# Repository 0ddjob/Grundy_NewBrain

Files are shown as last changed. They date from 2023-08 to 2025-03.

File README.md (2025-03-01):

# Grundy_NewBrain
Hopefully I can contribute something to the community.<br>

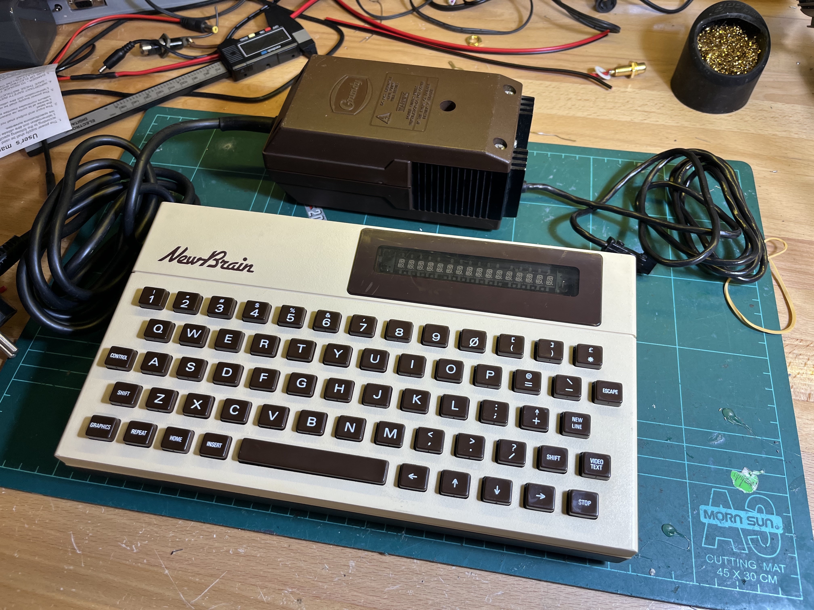
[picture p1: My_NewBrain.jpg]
My NewBrain


My current goal is to re-design the "store board" to use a 32KB SRAM instead of the two banks of 16KB DRAM.<br>

I think this is the last remaining fault in my machine.<br>

Failing ... or succeeding ... that, I'd like to try at a 64KB external SRAM board.<br>

{Fri 15-Sept-2023}<br>
Sent SRAM Store Board prototype for fabrication<br>
{Sat 1-Mar-2025}<br>
Well, what a disaster that was.  Fixed my (obvious) mistakes and have sent the updated design for fabrication.<br>

My YouTube video playlist - note, most are my very early videos so probably a bit rough:<br>
[https://www.youtube.com/playlist?list=PL5pwokf56wMKPswNvQZJsGPXETtgRD57M](https://www.youtube.com/playlist?list=PL5pwokf56wMKPswNvQZJsGPXETtgRD57M)

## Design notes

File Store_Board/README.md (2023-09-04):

# Grundy NewBrain Store Board

This is the internal RAM board in the NewBrain.<br>

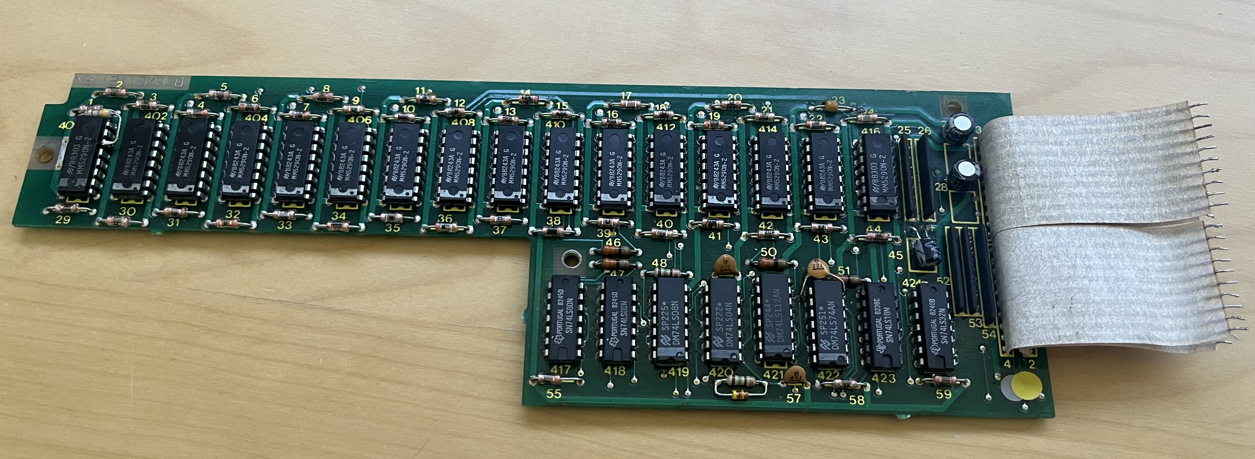
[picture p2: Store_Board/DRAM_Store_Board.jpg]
Original Store Board


It comprises two banks of 16KB, making 32KB in total.  Each bank has eight MM5290N-2 (16K x 1bit) DRAM chips.<br>

The DRAM is multiplexed using two RAS signals (RAS16 for bank 1 and RAS32 for bank 2) and one CAS signal.<br>

My idea to replace these DRAM with a single 32KB SRAM is as follows:<br>
- There are only eight address lines taken across to the store board: A0 to A6 & A14<br>
- As per other DRAM-to-SRAM designs, latch the RAS signals and apply with CAS<br>
- Simplify the two RAS16 & RAS32 signals to a single RAS signal for clocking the row address latch<br>

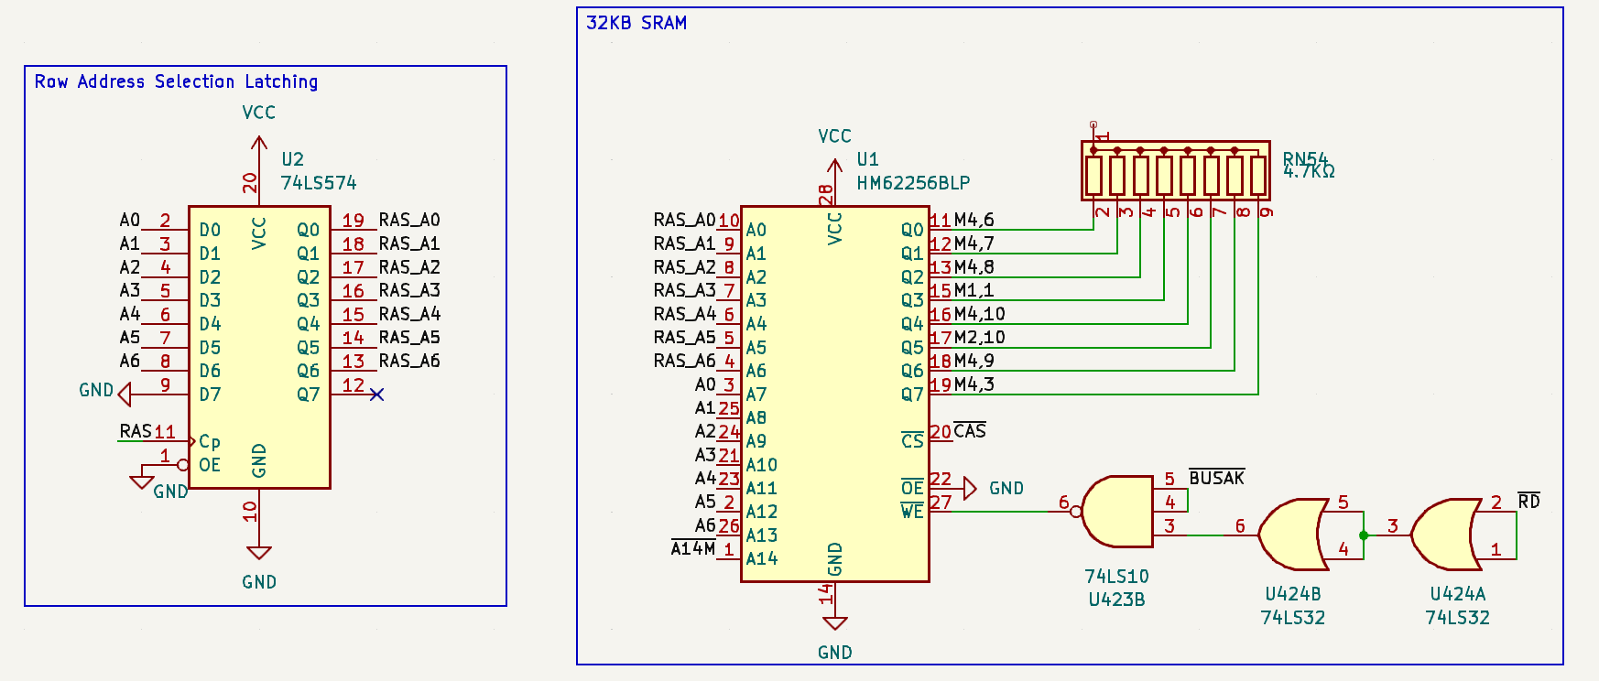
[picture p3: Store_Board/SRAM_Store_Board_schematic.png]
SRAM Store Board


Let's see ... (4-Sep-2023)<br>

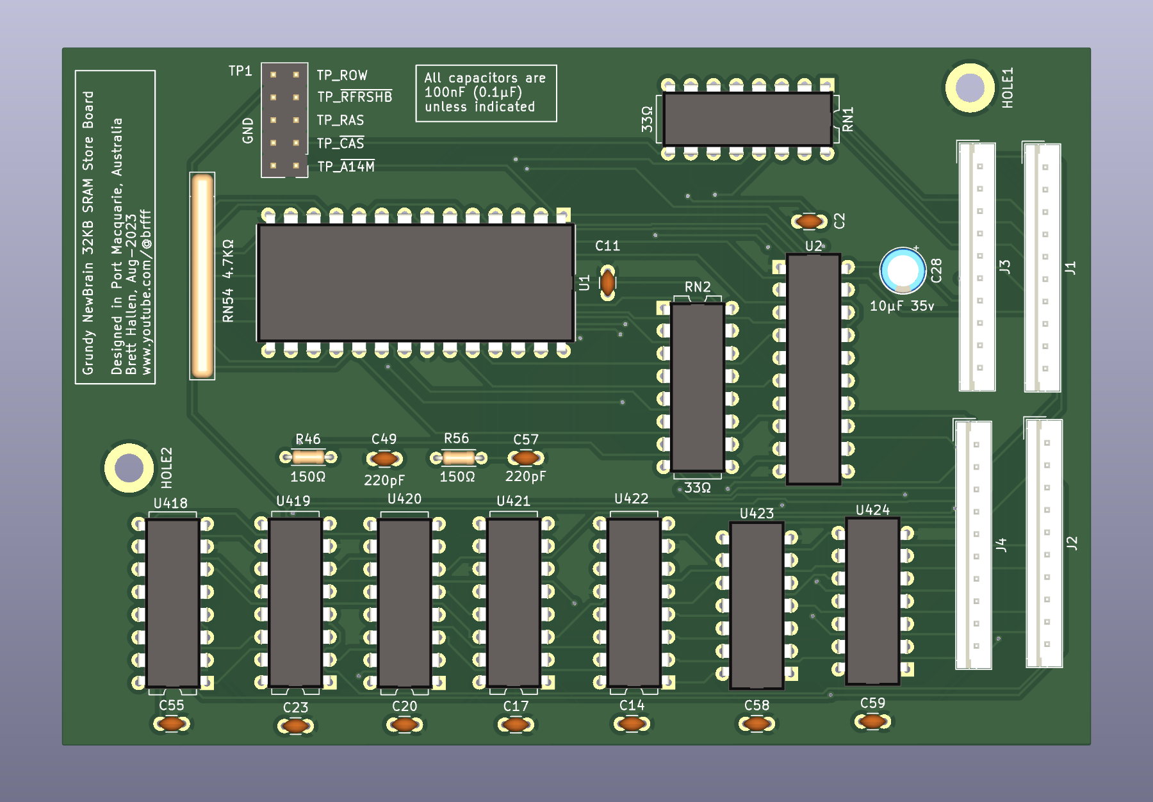
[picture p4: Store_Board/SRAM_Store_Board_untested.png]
SRAM Store Board PCB


Thanks to John Bradley for his Kicad schematics:<br>
https://github.com/flypie/NewBrain<br>

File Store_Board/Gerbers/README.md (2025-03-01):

# Grundy NewBrain Store Board

Please note that these are currently UNTESTED! <br>
Date: 1-Mar-2025 <br>

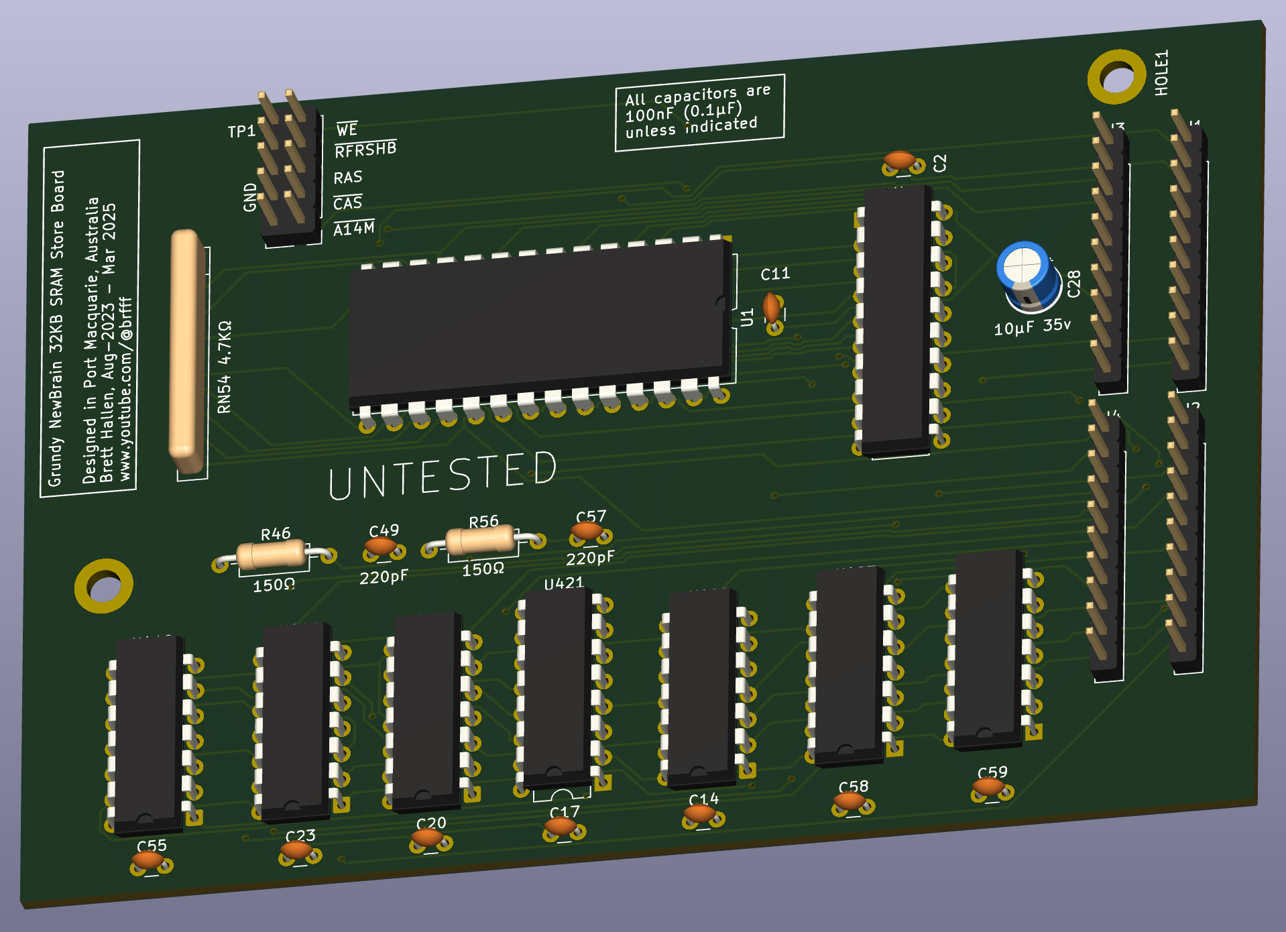
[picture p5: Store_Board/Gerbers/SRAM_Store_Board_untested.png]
SRAM Core Board


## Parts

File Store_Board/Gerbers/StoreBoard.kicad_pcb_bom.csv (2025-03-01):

Designator | Quantity | Value | Footprint | Package | MPN | DNP | Mount_Type
C11, C14, C17, C2, C20, C23, C55, C58, C59 | 9 | 100nF | C_Disc_D3.0mm_W1.6mm_P2.50mm |  |  |  | tht
C28 | 1 | 10µF 35v | CP_Radial_D5.0mm_P2.00mm |  |  |  | tht
C49, C57 | 2 | 220pF | C_Disc_D3.0mm_W1.6mm_P2.50mm |  |  |  | tht
HOLE1, HOLE2 | 2 | HOLE | MountingHole_3.2mm_M3_Pad |  |  |  | tht
J1, J2, J3, J4 | 4 | Conn_01x10 | PinHeader_1x10_P2.54mm_Vertical |  |  |  | tht
R46, R56 | 2 | 150Ω | R_Axial_DIN0207_L6.3mm_D2.5mm_P10.16mm_Horizontal |  |  |  | tht
RN54 | 1 | 4.7KΩ | R_Array_SIP9 |  |  |  | tht
TP1 | 1 | Conn_02x05_Odd_Even | PinHeader_2x05_P2.54mm_Vertical |  |  |  | tht
U1 | 1 | HM62256BLP | DIP-28_W15.24mm |  |  |  | tht
U2 | 1 | 74LS574 | DIP-20_W7.62mm |  |  |  | tht
U418 | 1 | 74LS00 | DIP-14_W7.62mm |  |  |  | tht
U419 | 1 | 74LS08 | DIP-14_W7.62mm |  |  |  | tht
U420 | 1 | 74LS04 | DIP-14_W7.62mm |  |  |  | tht
U421 | 1 | 74LS112 | DIP-16_W7.62mm |  |  |  | tht
U422 | 1 | SN74LS74 | DIP-14_W7.62mm |  |  |  | tht
U423 | 1 | 74LS10 | DIP-14_W7.62mm |  |  |  | tht
U424 | 1 | 74LS32 | DIP-14_W7.62mm |  |  |  | tht

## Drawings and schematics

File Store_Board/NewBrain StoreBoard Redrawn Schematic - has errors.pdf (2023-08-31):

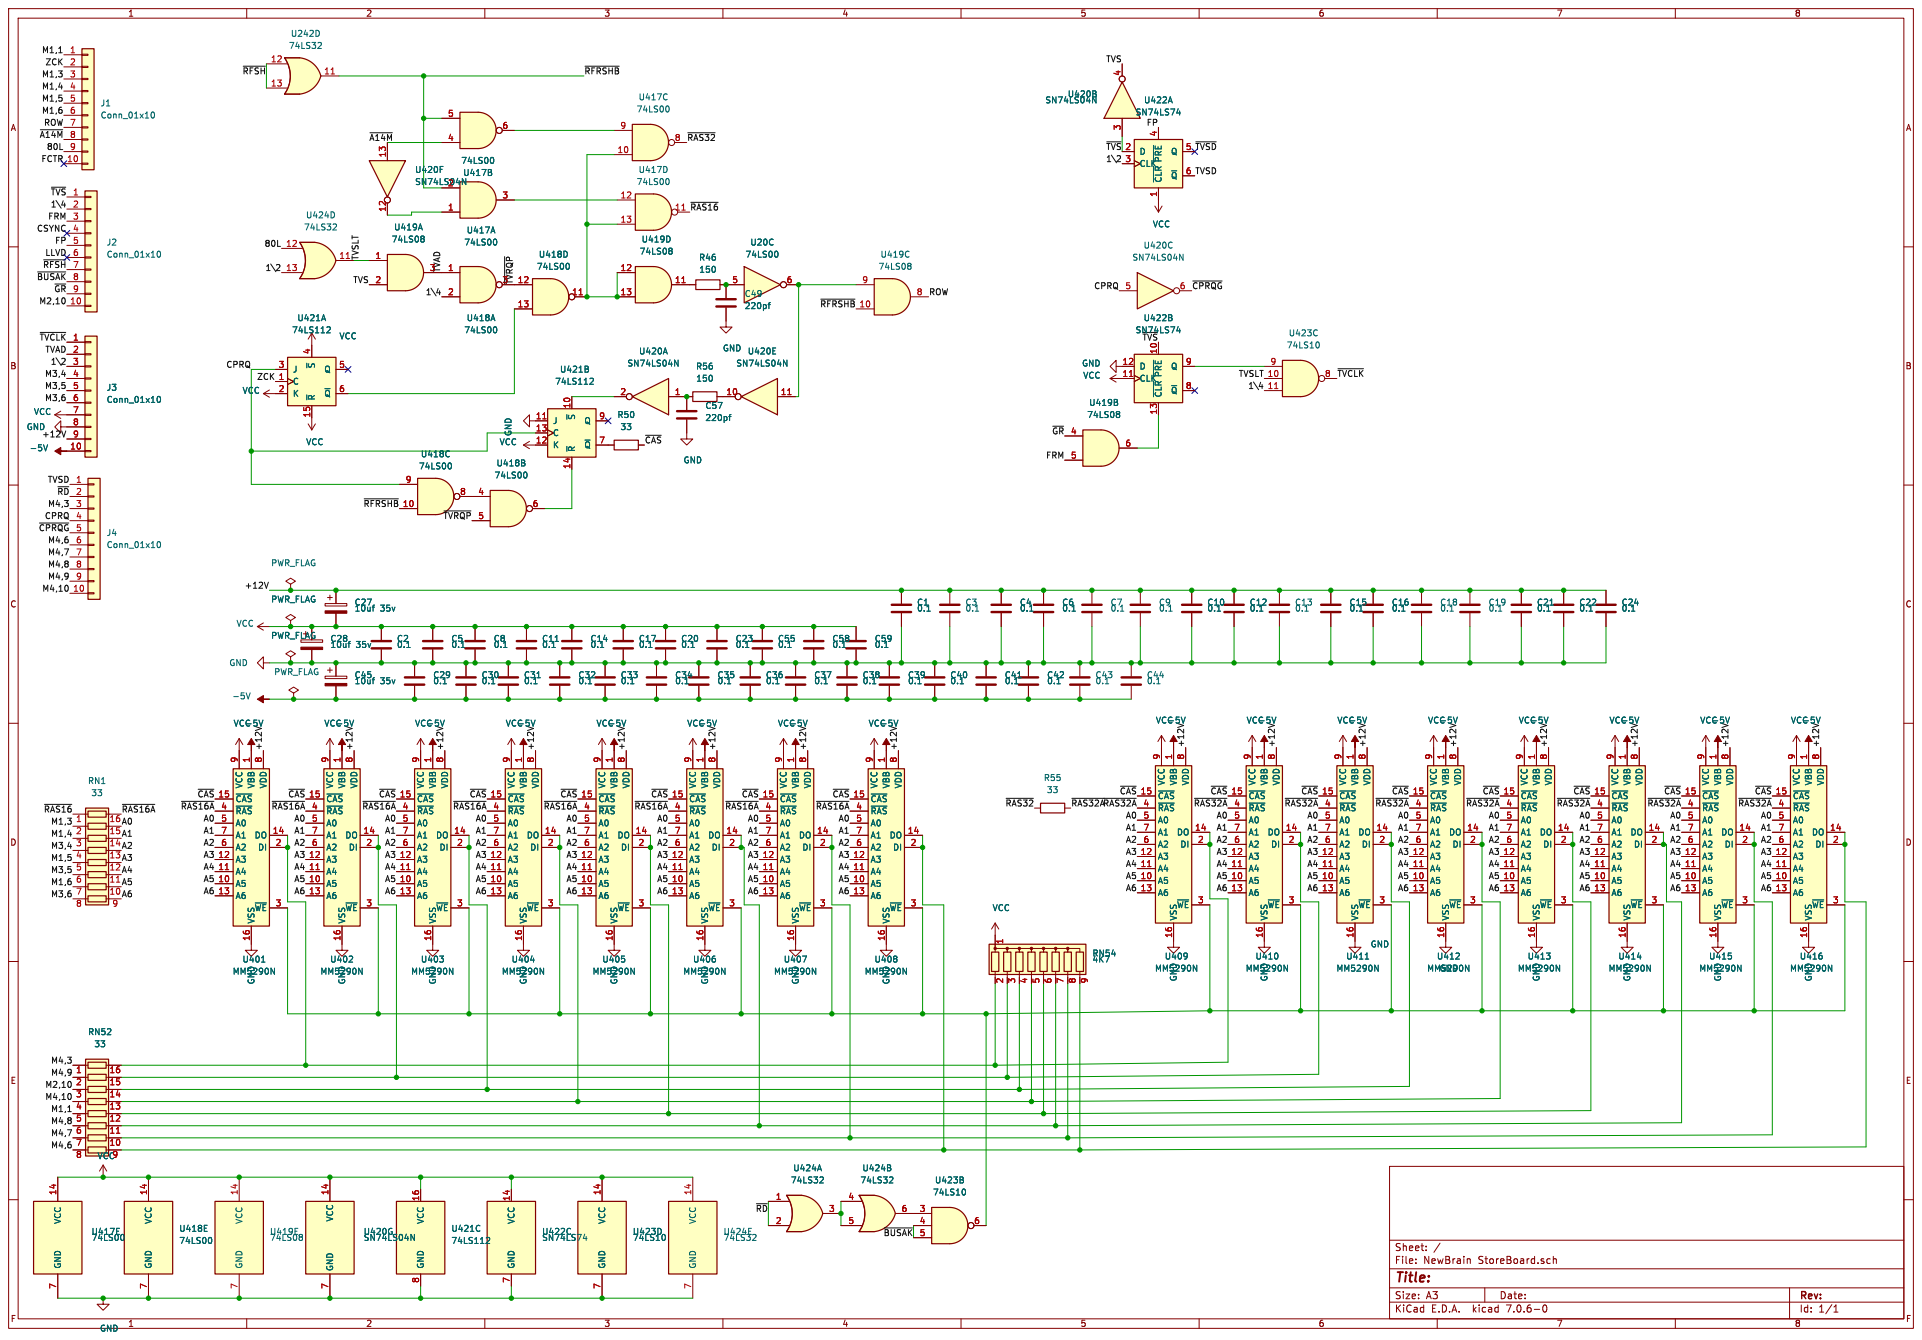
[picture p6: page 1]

7 VCC-5V VCC-5V GND GND

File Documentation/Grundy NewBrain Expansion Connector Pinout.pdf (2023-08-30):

1

49 | 25

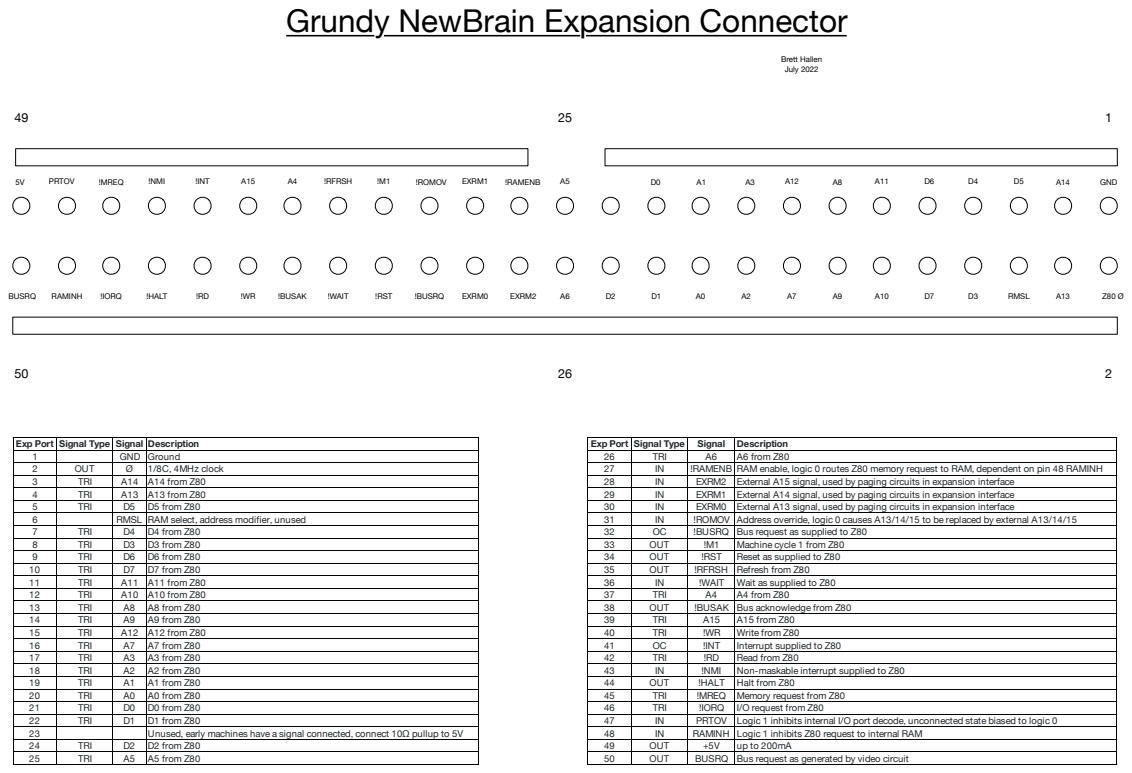
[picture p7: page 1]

Grundy NewBrain Expansion Connector

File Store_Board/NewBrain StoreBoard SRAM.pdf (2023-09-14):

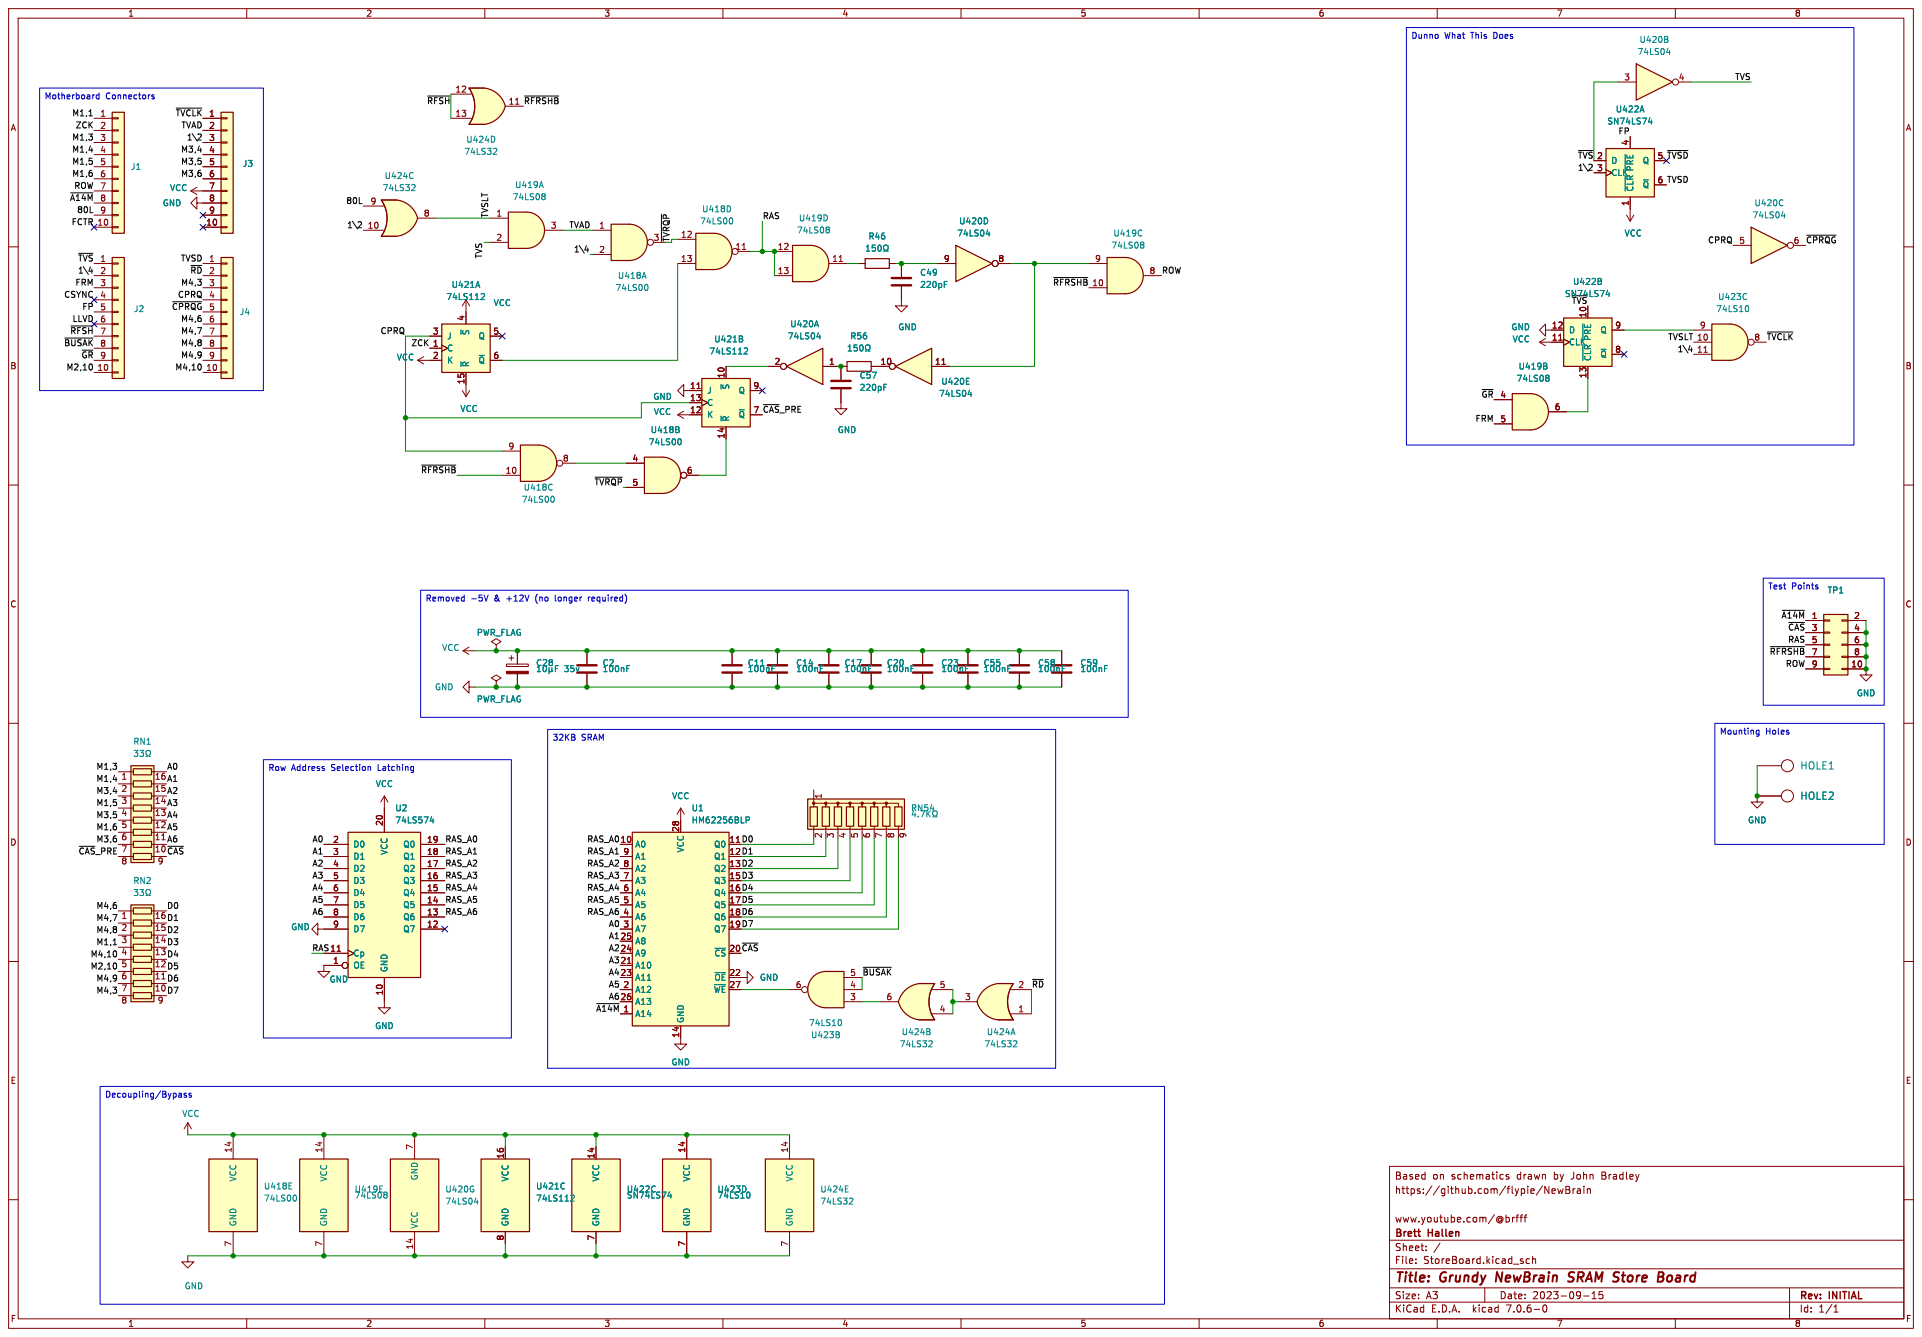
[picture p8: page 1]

~{TVSD} Removed -5V & +12V (no longer required)

Id: 1/1 Title: Grundy NewBrain SRAM Store Board

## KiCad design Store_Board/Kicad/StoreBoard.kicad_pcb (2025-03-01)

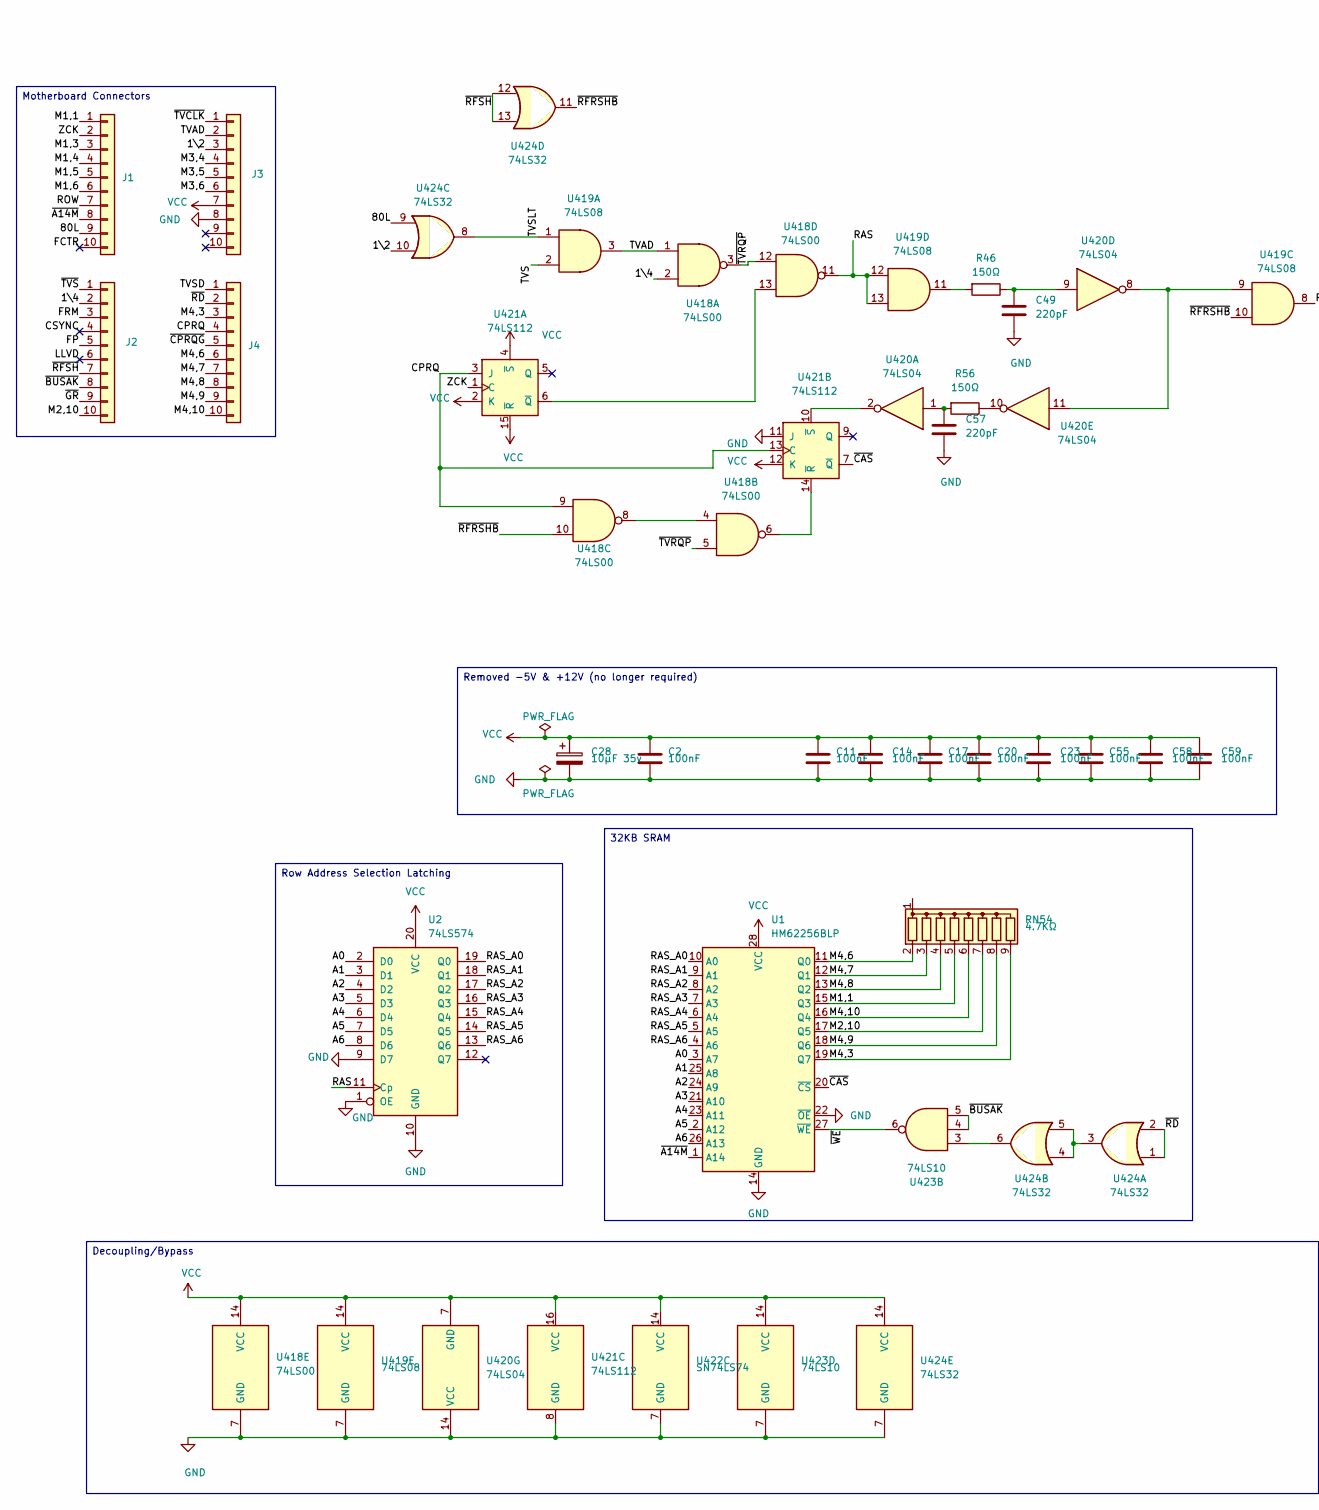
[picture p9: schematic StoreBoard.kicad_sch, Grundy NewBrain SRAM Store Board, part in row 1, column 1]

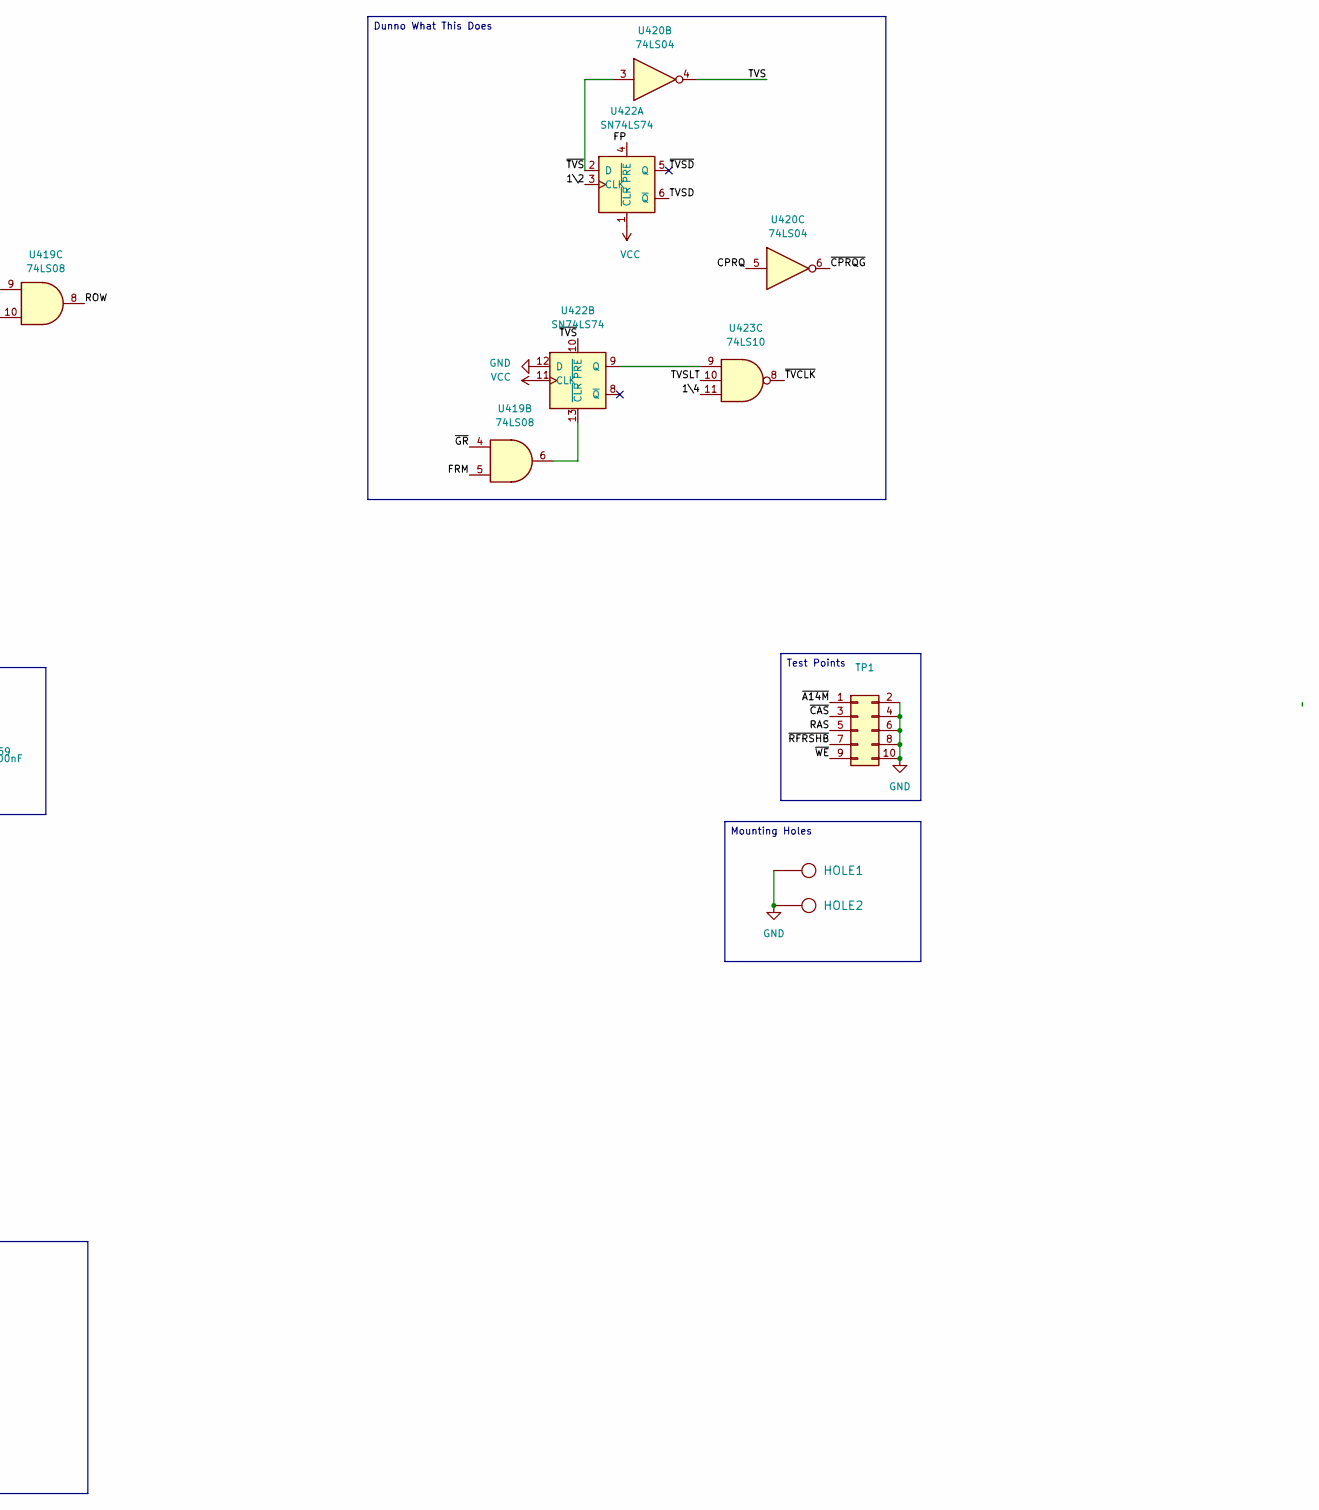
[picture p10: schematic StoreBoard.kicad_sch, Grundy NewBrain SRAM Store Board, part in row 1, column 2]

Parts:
C2, C11, C14, C17, C20, C23, C55, C58, C59: 100nF; C_Disc_D3.0mm_W1.6mm_P2.50mm
C28: 10µF 35v; CP_Radial_D5.0mm_P2.00mm
C49, C57: 220pF; C_Disc_D3.0mm_W1.6mm_P2.50mm
HOLE1, HOLE2: HOLE; MountingHole_3.2mm_M3_Pad
J1, J2, J3, J4: Conn_01x10; PinHeader_1x10_P2.54mm_Vertical
R46, R56: 150Ω; R_Axial_DIN0207_L6.3mm_D2.5mm_P10.16mm_Horizontal
RN54: 4.7KΩ; R_Array_SIP9
TP1: Conn_02x05_Odd_Even; PinHeader_2x05_P2.54mm_Vertical
U1: HM62256BLP; DIP-28_W15.24mm
U2: 74LS574; DIP-20_W7.62mm
U418: 74LS00; DIP-14_W7.62mm
U419: 74LS08; DIP-14_W7.62mm
U420: 74LS04; DIP-14_W7.62mm
U421: 74LS112; DIP-16_W7.62mm
U422: SN74LS74; DIP-14_W7.62mm
U423: 74LS10; DIP-14_W7.62mm
U424: 74LS32; DIP-14_W7.62mm

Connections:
/1\2: J3.3, U422.3 (CLK), U424.10
/1\4: J2.2, U418.2, U423.11
/80L: J1.9, U424.9
/A0: U1.3 (A7), U2.2 (D0)
/A1: U1.25 (A8), U2.3 (D1)
/A2: U1.24 (A9), U2.4 (D2)
/A3: U1.21 (A10), U2.5 (D3)
/A4: U1.23 (A11), U2.6 (D4)
/A5: U1.2 (A12), U2.7 (D5)
/A6: U1.26 (A13), U2.8 (D6)
/CPRQ: J4.4, U418.9, U420.5, U421.3 (J), U421.13 (C)
/CSYNC: J2.4
/FCTR: J1.10
/FP: J2.5, U422.4 (~PRE)
/FRM: J2.3, U419.5
/LLVD: J2.6
/M1,1: J1.1, RN54.5 (R4), U1.15 (Q3)
/M1,3: J1.3
/M1,4: J1.4
/M1,5: J1.5
/M1,6: J1.6
/M2,10: J2.10, RN54.7 (R6), U1.17 (Q5)
/M3,4: J3.4
/M3,5: J3.5
/M3,6: J3.6
/M4,3: J4.3, RN54.9 (R8), U1.19 (Q7)
/M4,6: J4.6, RN54.2 (R1), U1.11 (Q0)
/M4,7: J4.7, RN54.3 (R2), U1.12 (Q1)
/M4,8: J4.8, RN54.4 (R3), U1.13 (Q2)
/M4,9: J4.9, RN54.8 (R7), U1.18 (Q6)
/M4,10: J4.10, RN54.6 (R5), U1.16 (Q4)
/RAS: TP1.5, U2.11 (Cp), U418.11, U419.12, U419.13
/RAS_A0: U1.10 (A0), U2.19 (Q0)
/RAS_A1: U1.9 (A1), U2.18 (Q1)
/RAS_A2: U1.8 (A2), U2.17 (Q2)
/RAS_A3: U1.7 (A3), U2.16 (Q3)
/RAS_A4: U1.6 (A4), U2.15 (Q4)
/RAS_A5: U1.5 (A5), U2.14 (Q5)
/RAS_A6: U1.4 (A6), U2.13 (Q6)
/ROW: J1.7, U419.8
/TVAD: J3.2, U418.1, U419.3
/TVS: U419.2, U420.4
/TVSD: J4.1, U422.6 (~Q)
/TVSLT: U419.1, U423.10, U424.8
/ZCK: J1.2, U421.1 (C)
/~A14M: J1.8, TP1.1, U1.1 (A14)
/~BUSAK: J2.8, U423.4, U423.5
/~CAS: TP1.3, U1.20 (~CS), U421.7 (~Q)
/~CPRQG: J4.5, U420.6
/~GR: J2.9, U419.4
/~RD: J4.2, U424.1, U424.2
/~RFRSHB: TP1.7, U418.10, U419.10, U424.11
/~RFSH: J2.7, U424.12, U424.13
/~TVCLK: J3.1, U423.8
/~TVRQP: U418.3, U418.5, U418.12
/~TVSD: U422.5 (Q)
/~TVS: J2.1, U420.3, U422.2 (D), U422.10 (~PRE)
/~WE: TP1.9, U1.27 (~WE), U423.6
GND: C2.2, C11.2, C14.2, C17.2, C20.2, C23.2, C28.2, C49.2, C55.2, C57.2, C58.2, C59.2, HOLE1.1, HOLE2.1, J3.8, TP1.2, TP1.4, TP1.6, TP1.8, TP1.10, U1.14 (GND), U1.22 (~OE), U2.1 (OE), U2.9 (D7), U2.10 (GND), U418.7 (GND), U419.7 (GND), U420.14 (VCC), U421.8 (GND), U421.11 (J), U422.7 (GND), U422.12 (D), U423.7 (GND), U424.7 (GND)
unnamed: C49.1, R46.1, U420.9
unnamed: C57.1, R56.2, U420.1
unnamed: R46.2, U419.11
unnamed: R56.1, U420.10
unnamed: U418.4, U418.8
unnamed: U419.9, U420.8, U420.11
unnamed: U418.13, U421.6 (~Q)
unnamed: U418.6, U421.14 (~R)
unnamed: U420.2, U421.10 (~S)
unnamed: U422.9 (Q), U423.9
unnamed: U419.6, U422.13 (~CLR)
unnamed: U423.3, U424.6
unnamed: U424.3, U424.4, U424.5
VCC: C2.1, C11.1, C14.1, C17.1, C20.1, C23.1, C28.1, C55.1, C58.1, C59.1, J3.7, U1.28 (VCC), U2.20 (VCC), U418.14 (VCC), U419.14 (VCC), U420.7 (GND), U421.2 (K), U421.4 (~S), U421.12 (K), U421.15 (~R), U421.16 (VCC), U422.1 (~CLR), U422.11 (CLK), U422.14 (VCC), U423.14 (VCC), U424.14 (VCC)

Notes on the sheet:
32KB SRAM
Decoupling/Bypass
Row Address Selection Latching
Test Points
Mounting Holes
Motherboard Connectors
Removed -5V & +12V (no longer required)
Dunno What This Does

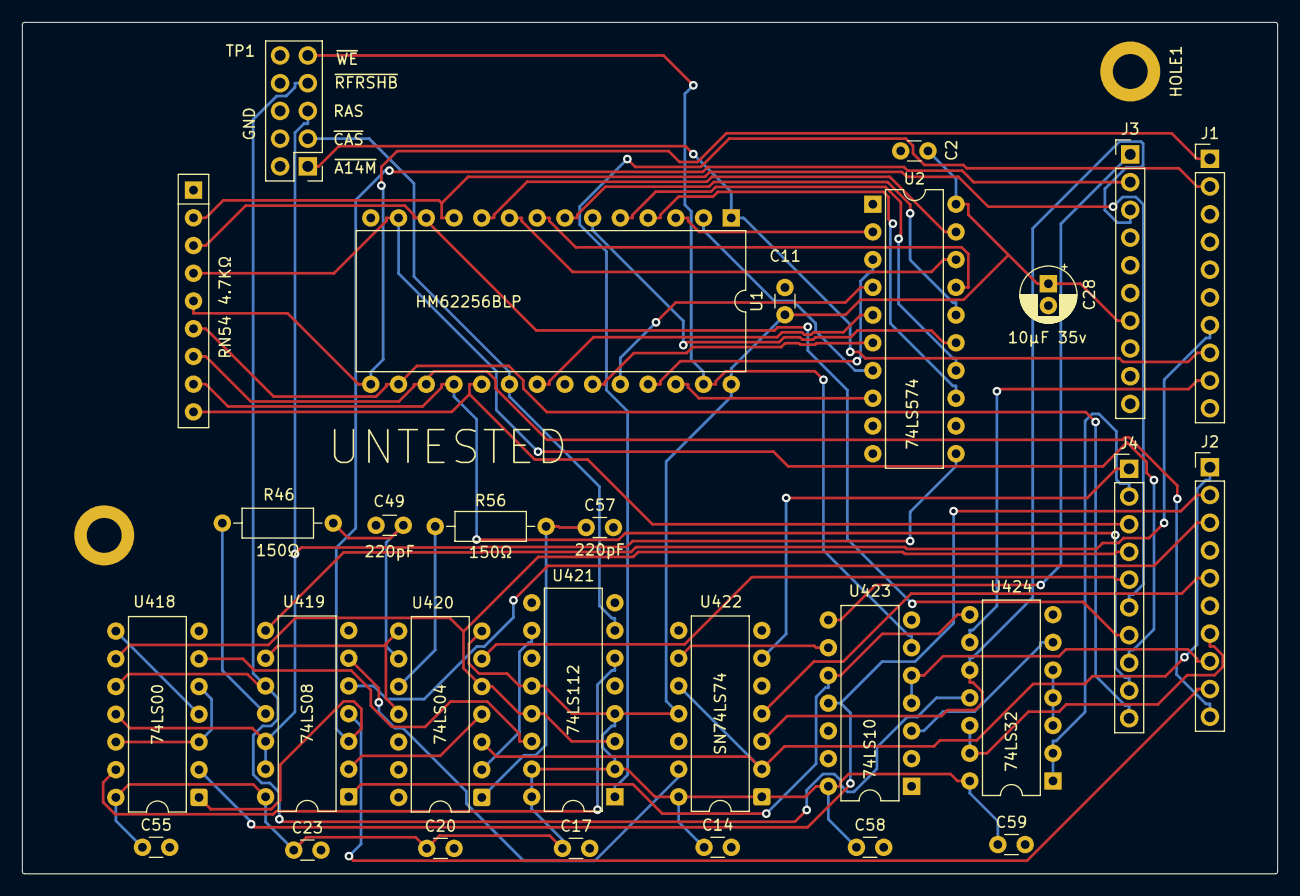
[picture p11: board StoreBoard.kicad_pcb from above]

Board: 2 copper layers, 115.0 x 78.0 mm, 31 parts (0 on the bottom side), 62 nets.

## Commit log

2023-08-30 Expansion connector pinout
2023-08-31 Initial 32KB SRAM Design
    [StoreBoard.kicad_pcb, StoreBoard.kicad_sch]
2023-08-31 Corrections to original schematic
    [StoreBoard.kicad_sch]
2023-08-31 PCB layout of (untested) SRAM Store Board
2023-08-31 PCB for testing
    [StoreBoard.kicad_pcb, StoreBoard.kicad_sch]
2023-08-31 PCB refinements
    [StoreBoard.kicad_sch]
2023-08-31 Ready for testing, I think
    [StoreBoard.kicad_pcb]
2023-08-31 Original DRAM schematic
2023-08-31 Updated SRAM schematic (work in progress)
2023-09-01 Added testpoints
    [StoreBoard.kicad_pcb, StoreBoard.kicad_sch]
2023-09-02 Further refinements
    [StoreBoard.kicad_pcb, StoreBoard.kicad_sch, StoreBoard_BOM.csv]
2023-09-04 Further refinements to RAS handling
    [StoreBoard.kicad_pcb, StoreBoard.kicad_sch]
2023-09-04 Noting the redrawn schematic has errors
2023-09-14 Final update before test fabrication
    [StoreBoard.kicad_pcb, StoreBoard.kicad_sch, StoreBoard_BOM.csv]
2023-09-15 Sent SRAM store board prototype for fabrication
2025-03-01 Corrected footprints
    [StoreBoard.kicad_pcb, StoreBoard.kicad_pcb_bom.csv, StoreBoard.kicad_pcb_positions.csv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]
2025-03-01 Updated Store Board 3D image
